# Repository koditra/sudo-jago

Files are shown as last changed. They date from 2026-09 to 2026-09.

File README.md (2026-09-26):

# sudo jago

sudo jago is a custom alarm clock built around the XIAO ESP32-C3.

It has a custom PCB, 3D printed case, ST7789 display, buzzer, and a 3x3 button matrix.

## Features

- Custom PCB
- Custom 3D printed case
- ST7789 TFT display
- 3x3 button matrix
- Built-in buzzer
- Creates its own Wi-Fi network
- Web portal for setting the time and alarm
- Button sequence required to stop the alarm

## Schematic



## PCB



## PCB Render



## 3D Case



## Full Assembly



## Hardware

- Seeed Studio XIAO ESP32-C3
- ST7789 TFT
- 9 buttons
- Buzzer
- Custom PCB
- 3D printed enclosure

## BOM

| Quantity | Part |
|---:|---|
| 1 | Seeed Studio XIAO ESP32-C3 |
| 1 | 2.25" ST7789 TFT display |
| 9 | MX-style mechanical switches |
| 9 | 1N4148 diodes |
| 1 | 3.3V piezo buzzer |
| 1 | 8-pin 2.54mm header |
| 8 | M3x5x4 heat-set inserts |
| 4 | M3x8mm screws |
| 4 | M3x16mm screws |
| 1 | Custom PCB |
| 1 | 3D printed case |

## Firmware

The ESP32 creates its own Wi-Fi network called `sudo jago`.

Connect to it and use the web portal to set the clock and alarm. The phone can then disconnect and sudo jago runs by itself.

When the alarm goes off, a random sequence appears on the display. The physical buttons must be pressed in the correct order to stop the alarm.

## Built By

Aashvik Goel (with blare.hackclub.com tutorial to help me out)

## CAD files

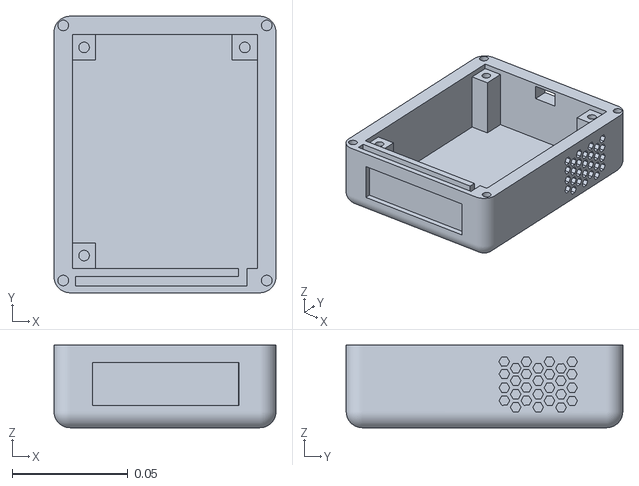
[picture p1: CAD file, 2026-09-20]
production/main-case.stl
0.096 x 0.12 x 0.0357

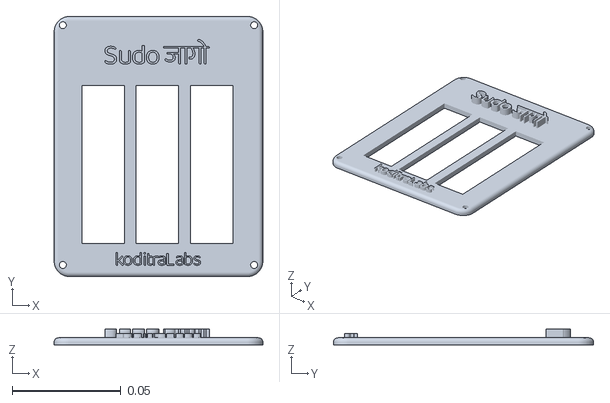
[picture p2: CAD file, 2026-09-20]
production/lid.stl
0.096 x 0.12 x 0.00731

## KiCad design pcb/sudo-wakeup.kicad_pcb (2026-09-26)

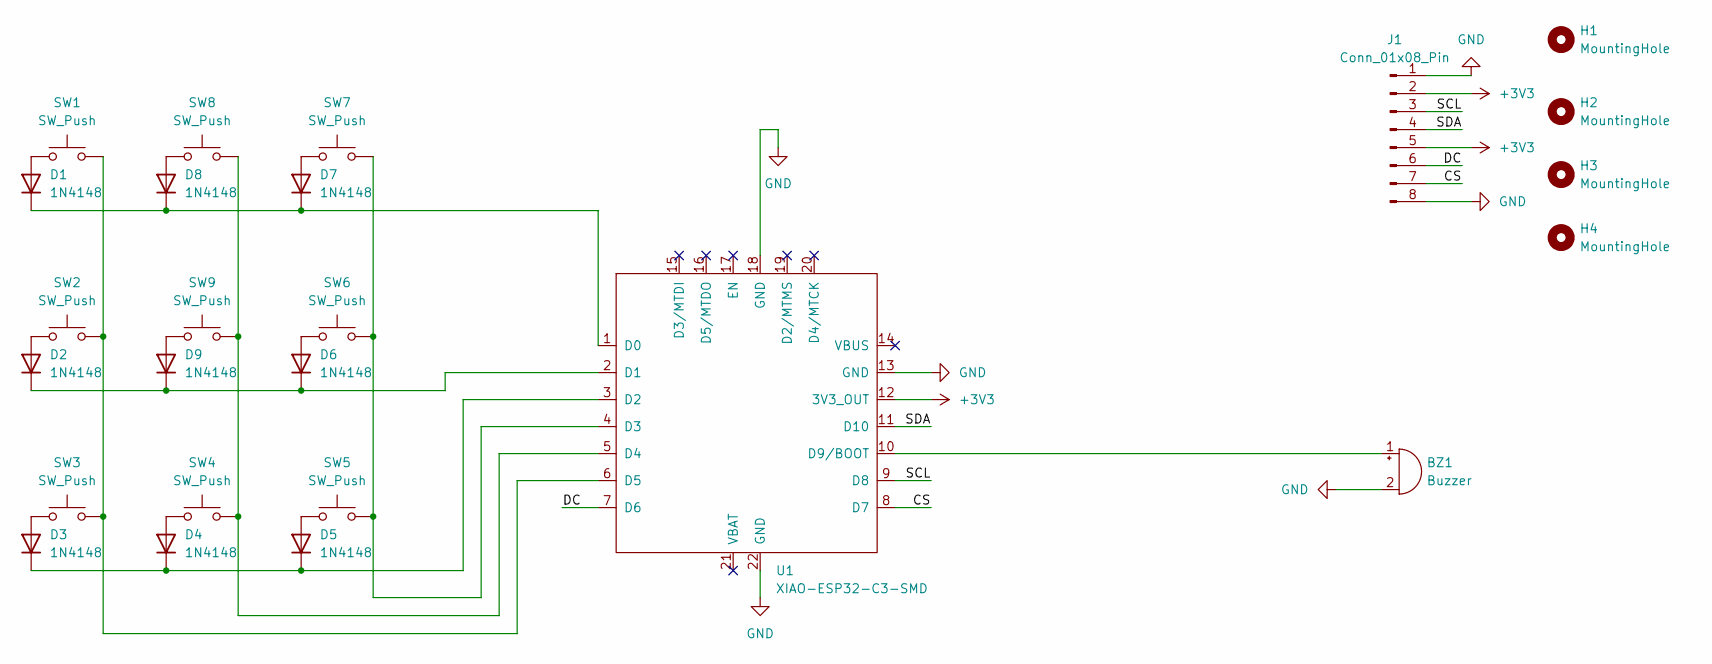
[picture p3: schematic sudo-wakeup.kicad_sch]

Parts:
BZ1: Buzzer; Buzzer_12x9.5RM7.6
D1, D2, D3, D4, D5, D6, D7, D8, D9: 1N4148; D_DO-35_SOD27_P7.62mm_Horizontal
H1, H2, H3, H4: MountingHole; MountingHole_3.2mm_M3
J1: Conn_01x08_Pin; PinSocket_1x08_P2.54mm_Vertical
SW1, SW2, SW3, SW4, SW5, SW6, SW7, SW8, SW9: SW_Push; SW_Cherry_MX_1.00u_PCB
U1: XIAO-ESP32-C3-SMD; XIAO-ESP32-C3-DIP

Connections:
+3V3: J1.2, J1.5, U1.12 (3V3_OUT)
/CS: J1.7, U1.8 (D7)
/DC: J1.6, U1.7 (D6)
/SCL: J1.3, U1.9 (D8)
/SDA: J1.4, U1.11 (D10)
GND: BZ1.2 (-), J1.1, J1.8, U1.13 (GND), U1.18 (GND), U1.22 (GND)
unnamed: BZ1.1 (+), U1.10 (D9/BOOT)
unnamed: D1.2 (A), SW1.1
unnamed: D1.1 (K), D7.1 (K), D8.1 (K), U1.1 (D0)
unnamed: D2.2 (A), SW2.1
unnamed: D2.1 (K), D6.1 (K), D9.1 (K), U1.2 (D1)
unnamed: D3.2 (A), SW3.1
unnamed: D3.1 (K), D4.1 (K), D5.1 (K), U1.3 (D2)
unnamed: D4.2 (A), SW4.1
unnamed: D5.2 (A), SW5.1
unnamed: D6.2 (A), SW6.1
unnamed: D7.2 (A), SW7.1
unnamed: D8.2 (A), SW8.1
unnamed: D9.2 (A), SW9.1
unnamed: SW5.2, SW6.2, SW7.2, U1.4 (D3)
unnamed: SW4.2, SW8.2, SW9.2, U1.5 (D4)
unnamed: SW1.2, SW2.2, SW3.2, U1.6 (D5)

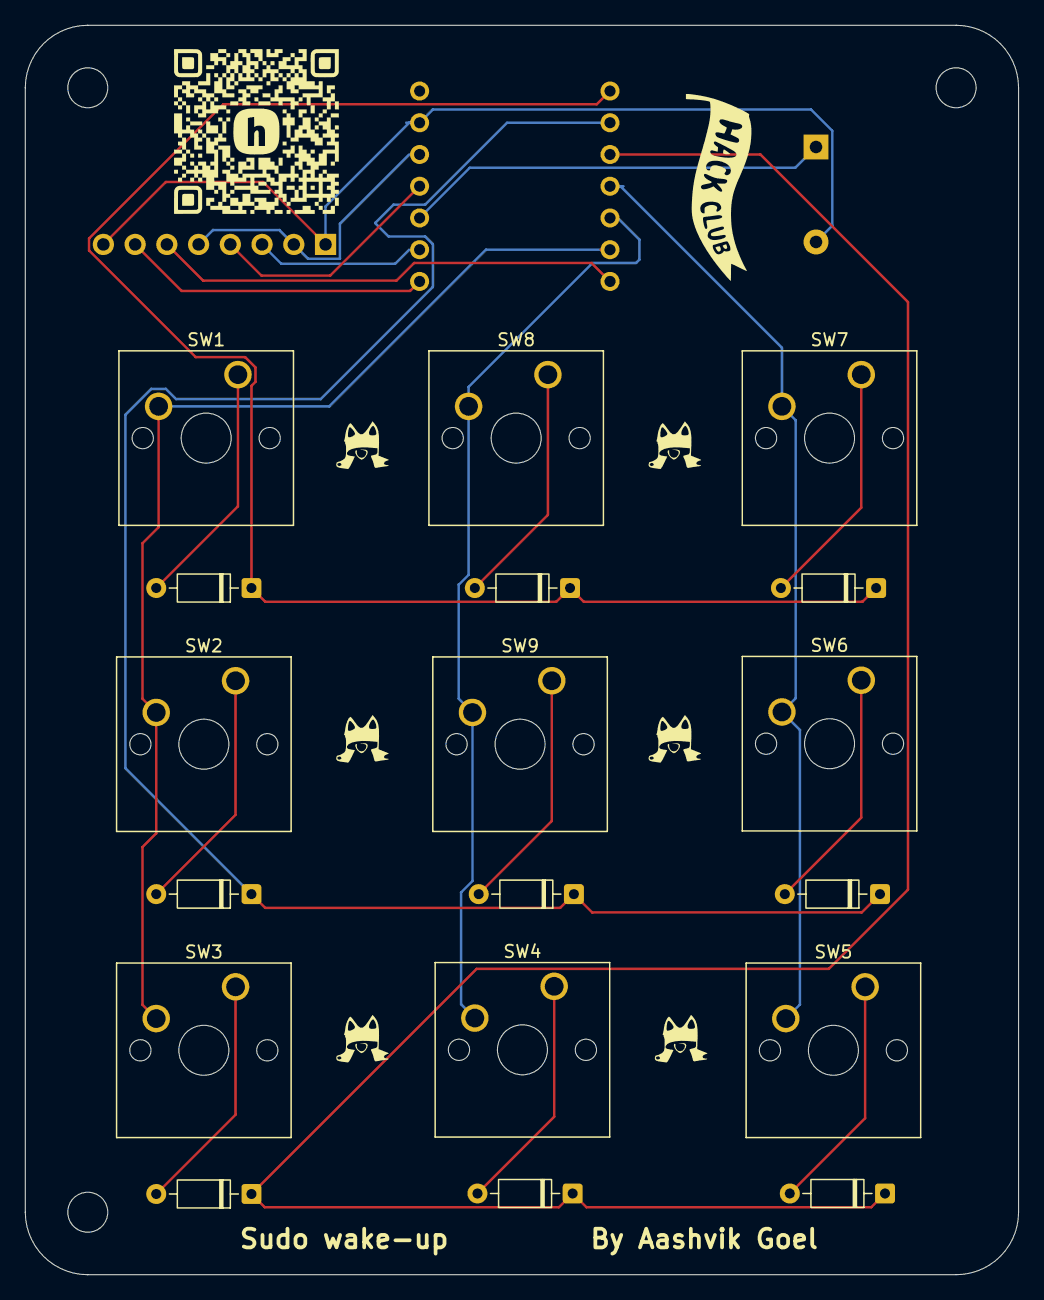
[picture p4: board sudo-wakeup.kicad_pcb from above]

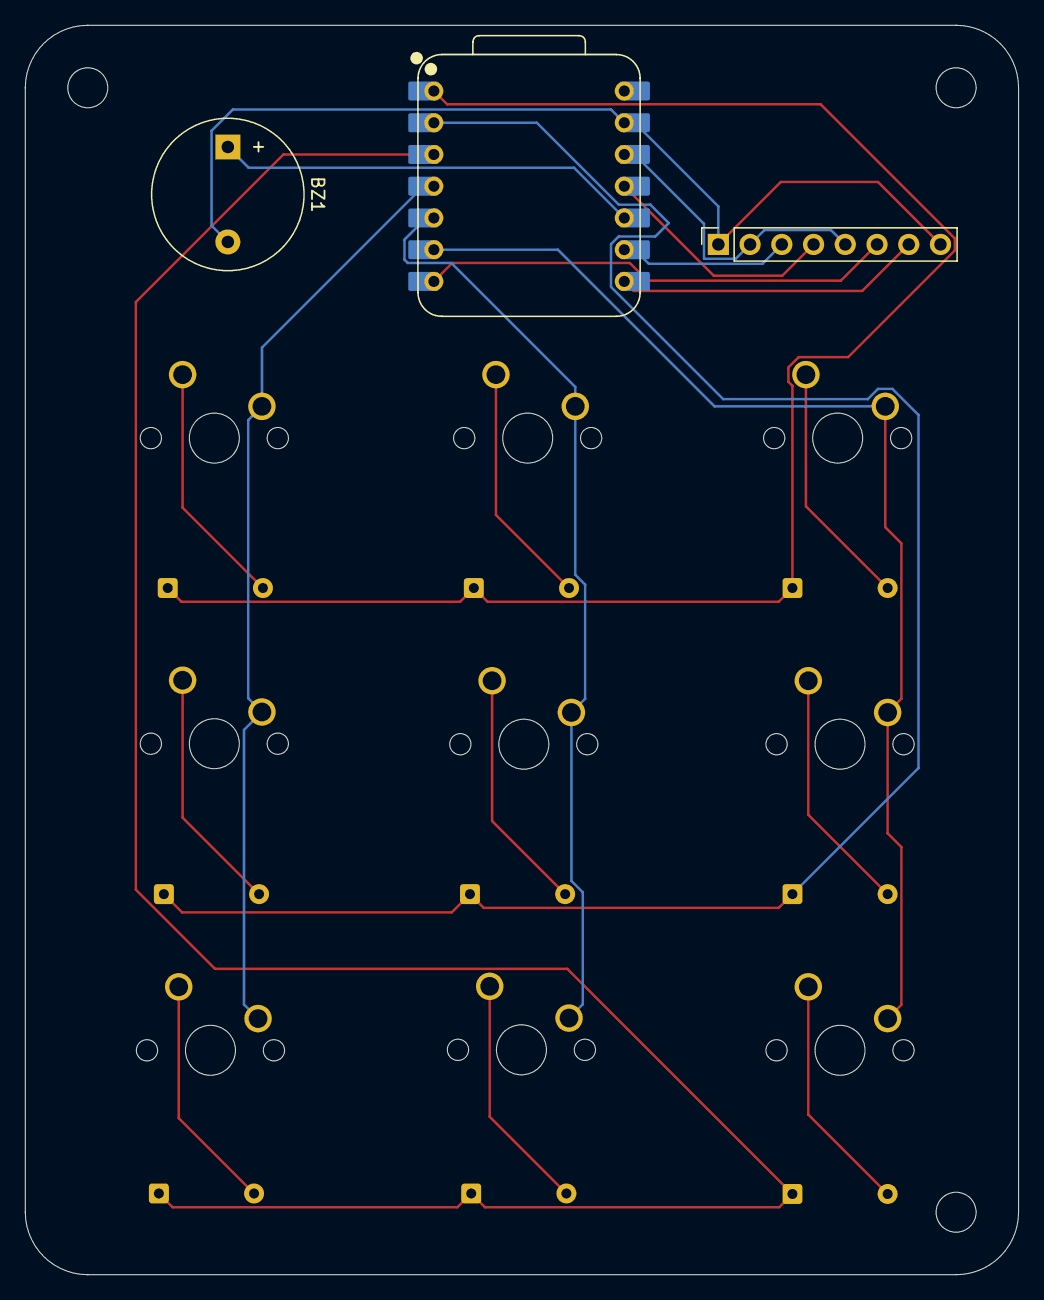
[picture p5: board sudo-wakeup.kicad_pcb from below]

Board: 2 copper layers, 79.5 x 100.0 mm, 24 parts (3 on the bottom side), 22 nets.

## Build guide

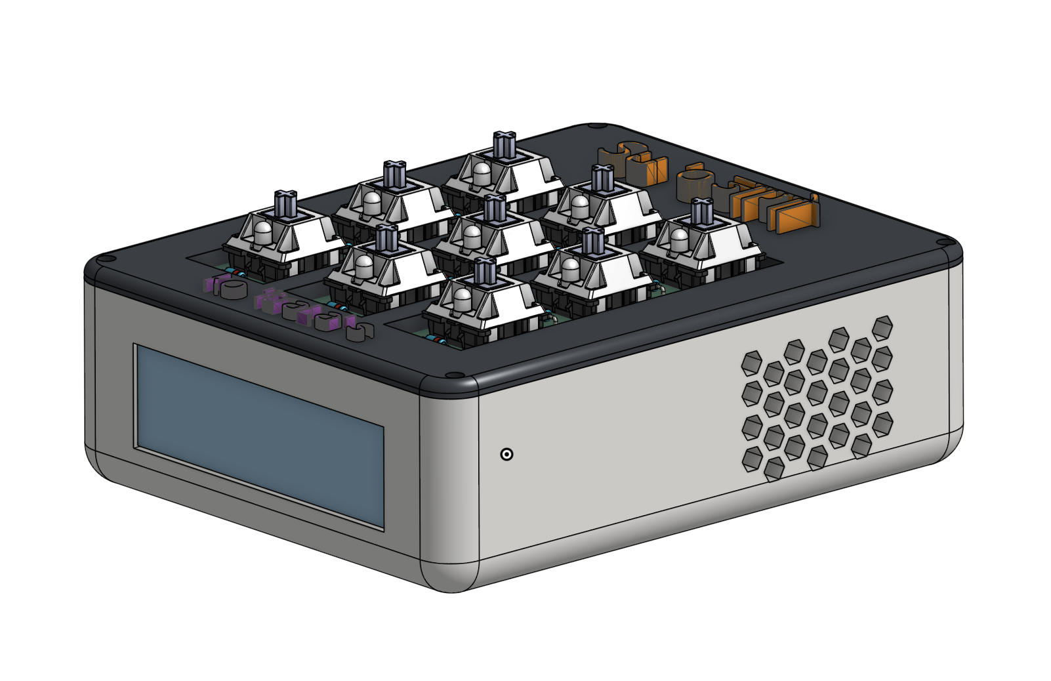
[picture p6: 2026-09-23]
images/assembly.png

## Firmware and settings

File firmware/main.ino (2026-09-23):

#include <Adafruit_GFX.h>
#include <Adafruit_ST7789.h>
#include <SPI.h>
#include <WiFi.h>
#include <WebServer.h>
#include <DNSServer.h>
#include <Preferences.h>
#include <time.h>

#define TFT_MOSI 10
#define TFT_SCLK 8
#define TFT_CS 7
#define TFT_DC 6
#define TFT_RST -1
#define BUZZER 9

const int rows[3] = {0, 1, 2};
const int cols[3] = {5, 4, 3};

const int buttons[3][3] = {
  {1, 8, 7},
  {2, 9, 6},
  {3, 4, 5}
};

Adafruit_ST7789 tft(TFT_CS, TFT_DC, TFT_MOSI, TFT_SCLK, TFT_RST);
WebServer server(80);
DNSServer dns;
Preferences prefs;

bool last[3][3] = {};
bool alarmActive = false;
bool alarmSet = false;
bool buzz = false;

int alarmHour, alarmMinute;
int sequence[4];
int position = 0;

unsigned long lastPress = 0;
unsigned long lastBuzz = 0;
int lastAlarmMinute = -1;

void setup() {
  Serial.begin(115200);

  for (int r = 0; r < 3; r++) {
    pinMode(rows[r], OUTPUT);
    digitalWrite(rows[r], HIGH);
  }

  for (int c = 0; c < 3; c++)
    pinMode(cols[c], INPUT_PULLUP);

  pinMode(BUZZER, OUTPUT);

  tft.init(76, 284);
  tft.setRotation(1);
  tft.fillScreen(ST77XX_BLACK);

  prefs.begin("jago", false);
  alarmHour = prefs.getInt("hour", 7);
  alarmMinute = prefs.getInt("min", 0);
  alarmSet = prefs.getBool("set", false);

  WiFi.mode(WIFI_AP);
  WiFi.softAP("sudo jago", "sudojago");

  dns.start(53, "*", WiFi.softAPIP());

  server.on("/", portal);
  server.on("/clock", HTTP_POST, setClock);
  server.on("/alarm", HTTP_POST, setAlarm);
  server.on("/off", HTTP_POST, disableAlarm);
  server.onNotFound(portal);
  server.begin();

  Serial.print("Portal: http://");
  Serial.println(WiFi.softAPIP());

  showReady();
}

void loop() {
  dns.processNextRequest();
  server.handleClient();
  scanButtons();

  if (alarmActive)
    updateBuzzer();

  checkAlarm();
}

void portal() {
  String page =
    "<html><meta name='viewport' content='width=device-width'>"
    "<style>body{font-family:Arial;background:#111;color:white;"
    "max-width:400px;margin:40px auto;padding:20px}"
    "input,button{width:100%;padding:14px;margin:8px 0;font-size:18px}"
    "button{border:0;border-radius:8px}</style>"
    "<h1>sudo jago</h1>"
    "<p>Set the clock and alarm.</p>"
    "<button onclick='clock()'>Set Clock</button>"
    "<input id='alarm' type='time'>"
    "<button onclick='setAlarm()'>Set Alarm</button>"
    "<button onclick='off()'>Disable Alarm</button>"
    "<script>"
    "function post(u,d){fetch(u,{method:'POST',body:d}).then(()=>location.reload())}"
    "function clock(){post('/clock',Date.now().toString())}"
    "function setAlarm(){post('/alarm',document.getElementById('alarm').value)}"
    "function off(){post('/off','')}"
    "</script></html>";

  server.send(200, "text/html", page);
}

void setClock() {
  unsigned long long ms = server.arg("plain").toInt();
  time_t now = ms / 1000;

  timeval tv = {now, 0};
  settimeofday(&tv, nullptr);

  server.send(200, "text/plain", "OK");
}

void setAlarm() {
  String t = server.arg("plain");

  if (t.length() >= 5) {
    alarmHour = t.substring(0, 2).toInt();
    alarmMinute = t.substring(3, 5).toInt();

    alarmSet = true;

    prefs.putInt("hour", alarmHour);
    prefs.putInt("min", alarmMinute);
    prefs.putBool("set", true);
  }

  server.send(200, "text/plain", "OK");
  showReady();
}

void disableAlarm() {
  alarmSet = false;
  prefs.putBool("set", false);

  server.send(200, "text/plain", "OK");
  showReady();
}

void checkAlarm() {
  if (!alarmSet || alarmActive)
    return;

  tm timeinfo;

  if (!getLocalTime(&timeinfo, 5))
    return;

  if (timeinfo.tm_hour == alarmHour &&
      timeinfo.tm_min == alarmMinute &&
      lastAlarmMinute != timeinfo.tm_min) {

    lastAlarmMinute = timeinfo.tm_min;
    startAlarm();
  }
}

void startAlarm() {
  alarmActive = true;
  position = 0;

  for (int i = 0; i < 4; i++)
    sequence[i] = random(1, 10);

  showAlarm();

  Serial.print("Sequence: ");

  for (int i = 0; i < 4; i++) {
    Serial.print(sequence[i]);
    Serial.print(" ");
  }

  Serial.println();
}

void stopAlarm() {
  alarmActive = false;
  noTone(BUZZER);
  showReady();
}

void updateBuzzer() {
  if (millis() - lastBuzz < 300)
    return;

  lastBuzz = millis();
  buzz = !buzz;

  if (buzz)
    tone(BUZZER, 2200);
  else
    noTone(BUZZER);
}

void scanButtons() {
  for (int r = 0; r < 3; r++) {
    for (int i = 0; i < 3; i++)
      digitalWrite(rows[i], HIGH);

    digitalWrite(rows[r], LOW);

    for (int c = 0; c < 3; c++) {
      bool pressed = digitalRead(cols[c]) == LOW;

      if (pressed && !last[r][c] &&
          millis() - lastPress > 100) {
        lastPress = millis();
        handleButton(buttons[r][c]);
      }

      last[r][c] = pressed;
    }
  }
}

void handleButton(int button) {
  if (!alarmActive)
    return;

  if (button == sequence[position]) {
    position++;

    if (position == 4)
      stopAlarm();
    else
      showAlarm();
  } else {
    position = 0;
    showAlarm();
  }
}

void showReady() {
  tft.fillScreen(ST77XX_BLACK);
  tft.setTextColor(ST77XX_WHITE);

  tft.setTextSize(3);
  tft.setCursor(92, 5);
  tft.print("BLARE");

  tft.setTextSize(1);
  tft.setCursor(91, 38);
  tft.print("sudo jago");

  tft.setCursor(10, 60);

  if (alarmSet) {
    tft.print("ALARM ");
    if (alarmHour < 10) tft.print("0");
    tft.print(alarmHour);
    tft.print(":");
    if (alarmMinute < 10) tft.print("0");
    tft.print(alarmMinute);
  } else {
    tft.print("ALARM OFF");
  }
}

void showAlarm() {
  tft.fillScreen(ST77XX_BLACK);
  tft.setTextColor(ST77XX_WHITE);
  tft.setTextSize(2);

  tft.setCursor(92, 3);
  tft.print("WAKE UP");

  tft.setTextSize(1);
  tft.setCursor(88, 23);
  tft.print("PRESS IN ORDER");

  tft.setTextSize(2);

  for (int i = 0; i < 4; i++) {
    tft.setCursor(82 + i * 32, 42);

    if (i < position)
      tft.setTextColor(ST77XX_GREEN);
    else
      tft.setTextColor(ST77XX_WHITE);

    tft.print(sequence[i]);
  }
}

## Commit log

2026-09-20 added production 3d files :D
    [lid.stl, main-case.stl]
2026-09-21 Add main firmware code for TFT display and buttons
    Initialize TFT display and set up button scanning.
2026-09-21 Implement showClock and scanButtons functions
    Added functions to display clock and scan buttons.
2026-09-23 Implement web server for alarm and clock management
    Added web server functionality for clock and alarm settings, including handling requests to set and disable alarms. Integrated preferences storage for alarm settings and improved button handling.
2026-09-26 added files/organization + added BOM
    [sudo-wakeup.kicad_pcb, sudo-wakeup.kicad_sch]
